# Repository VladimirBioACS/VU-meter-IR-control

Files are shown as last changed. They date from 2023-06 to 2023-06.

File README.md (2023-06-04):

# VU-Meter digital control firmware
This is a simple firmware for the Audio VU meter. The firmware implements the IR remote control of the device.

## System architecture

The picture below shows top-level system architecture:

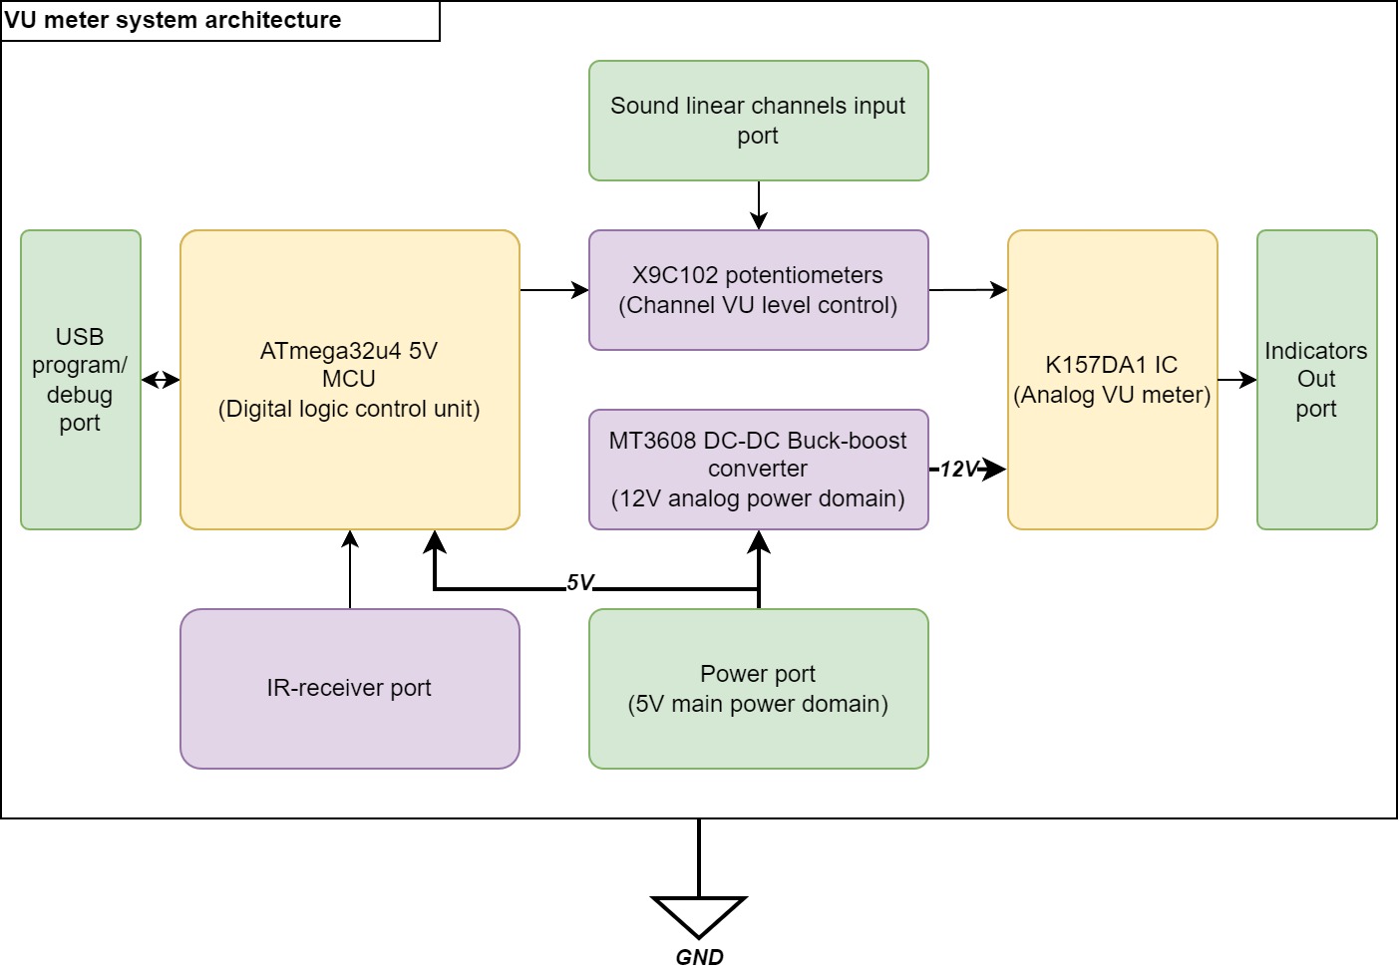
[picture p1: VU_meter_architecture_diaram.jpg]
System diagram


- USB program/debug port is used for programming and debugging process. It is disabled during normal operation. To use debug functionality the specified macro should be set in the code;
- ATMega32u4 5V MCU - digital logic control unit. Main part of the digital control subsystem. Controls the X9C102 potentiometers and receives controlling CMD`s via IR-receiver port;
- K157DA1 IC: analog VU meter IC. Used as a controller for the analog sound level indication gauges;
- MT3608 DC-DC Buck-boost converter: main power supply for the K157DA1 IC domain. Outputs 12V DC. As input takes 5V from power port and boost it to the 12V;
- X9C102 ICs: digital potentiometers (0 - 100K). Used as power limiter for the sound linear channels. The resistance range of the X9C102 IC`s limited with software to the 30K max. One X9C102 step equals to 3K. Maximum value: 42K; minimum value: 3K (14 steps in general);
- IR-receiver port: 2-pin port, used for  IR-receiving diode connection;
- Power port: main power port for the device (strictly 5V);
- Sound linear channel input port: input port for left and right sound channels;
- Indicators Out port: output port for the analog sound level indication gauges.

## Device 3D model

The picture below shows 3D model of the VU-meter device

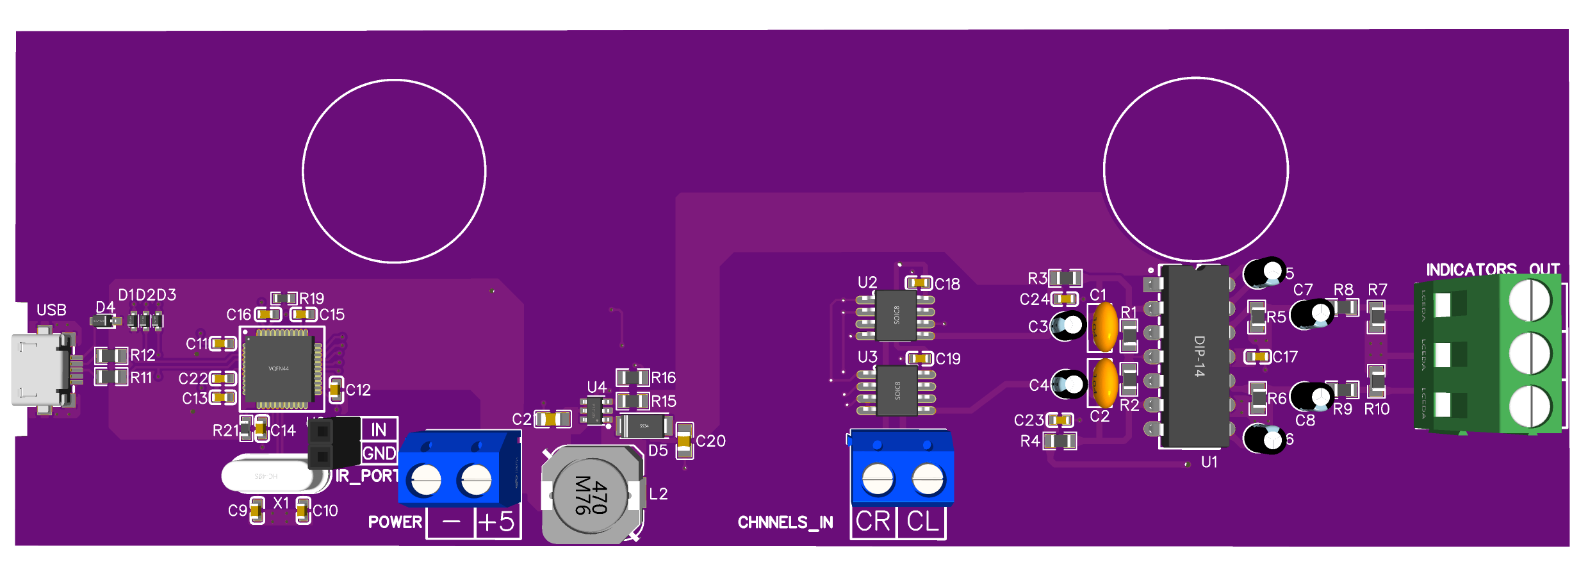
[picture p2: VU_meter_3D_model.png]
3D diagram


## Project structure

Root folder contains platformio.ini configuration and additional (README.md, pictures, build.py etc) files.
Folder structure:
- **src**: contains project source files;
- **include**: contains project header files;
- **lib**: contains project specific (private) libraries;
- **test**: contains unit tests;
- **PCB_designb**: contains HW related files (schematic; gerbers and EasyEDA project);
- **.vscode**: contains VS Code config;
- **Profiler_application**: contains the profiler application flow for the Node-RED.

## How to add custom IR-Remote

To add a remote to control the device you need:
- Set the **DEBUG_PRINTER** and **DEBUG_IR_FULL_INFO** options to **STD_ON**
- Upload firmware to the device and open serial port;
- Start pressing buttons on the remote. You should get a debug output with full information about the IR protocol. The necessary info are stored in IR CMD values;
- Save the IR CMD values and write it to the **protocol.h** header file to the corresponding #define constant.

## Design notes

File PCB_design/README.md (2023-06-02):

# VU-meter Schematic
This folder contains schematic; gerbers and EasyEDA project files for VU-meter device.

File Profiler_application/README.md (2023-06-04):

# Profiler application

This folder contains the Node-RED flow for the profiler application. The Node-RED (https://nodered.org/docs/getting-started/local) need to be installed on the host machine in order to run this application flow.

To import project into Node-RED use this guide: https://nodered.org/docs/user-guide/editor/workspace/import-export

## Profiler application demo:

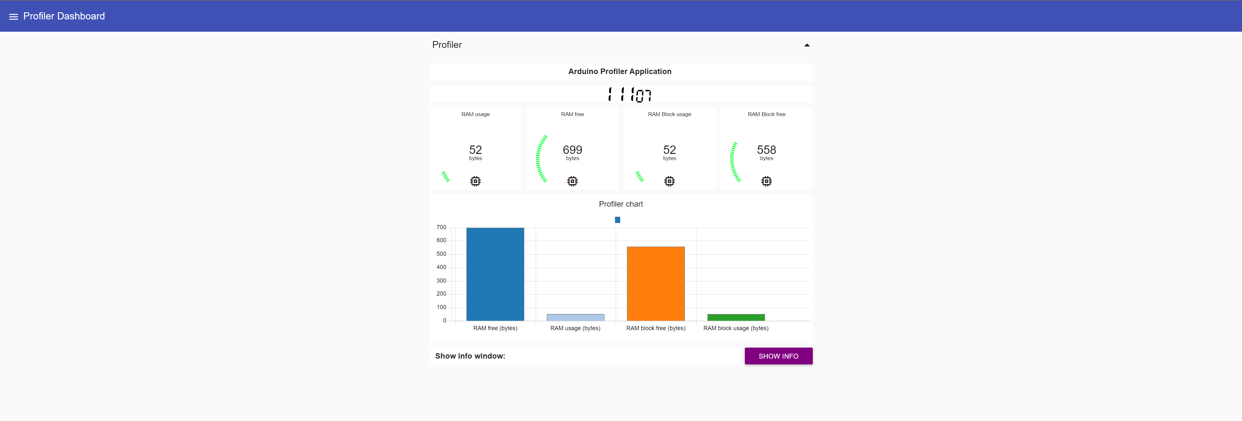
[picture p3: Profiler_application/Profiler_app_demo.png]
Profiler app demo


## Profiler description

Simple profiler for Arduino applications, based on Node-RED and ArduinoProfiler + ArduinoJson libs.
Profiler receives JSON data from target device from UART interface. The data contains:

- RAM usage in bytes;
- Free RAM in bytes;
- RAM block usage in bytes;
- Free RAM block in bytes.

## How to use profiler

To be able to use profiler you need to perform next steps:

- Enable the **ARDUINO_PROFILER** and **DEBUG_PRINTER** options in the **main.h** file;
- Compile and upload firmware to the target device;
- Install the Node-RED on your host machine, using the guide provided in first section, and import the profiler.json to the Node-RED environmetn (use the guide provided in first section);
- Check the COM port to which target device is connected and change it (if needed) in profiler.json UART configuration;
- Connect the target device to PC and  open the web application with http://localhost:1880/ui.

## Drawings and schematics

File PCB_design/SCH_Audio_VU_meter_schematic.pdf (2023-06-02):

A | A

1

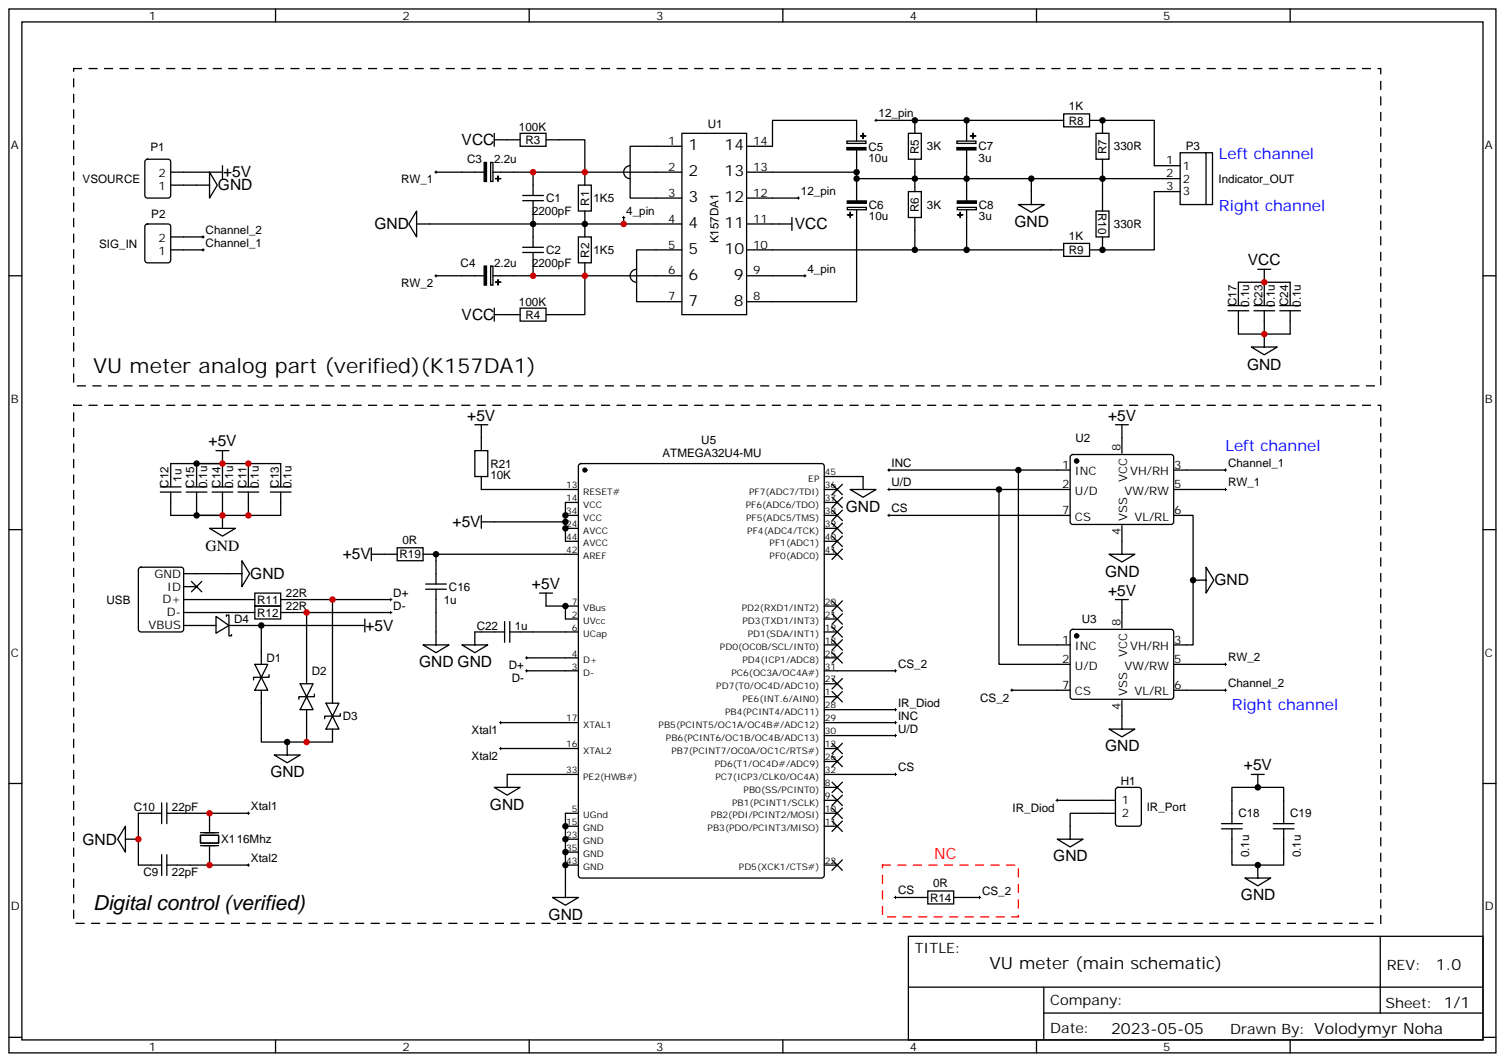
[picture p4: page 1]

VU meter analog part (verified)(K157DA1)

Drawn By: Volodymyr Noha

A | A

1

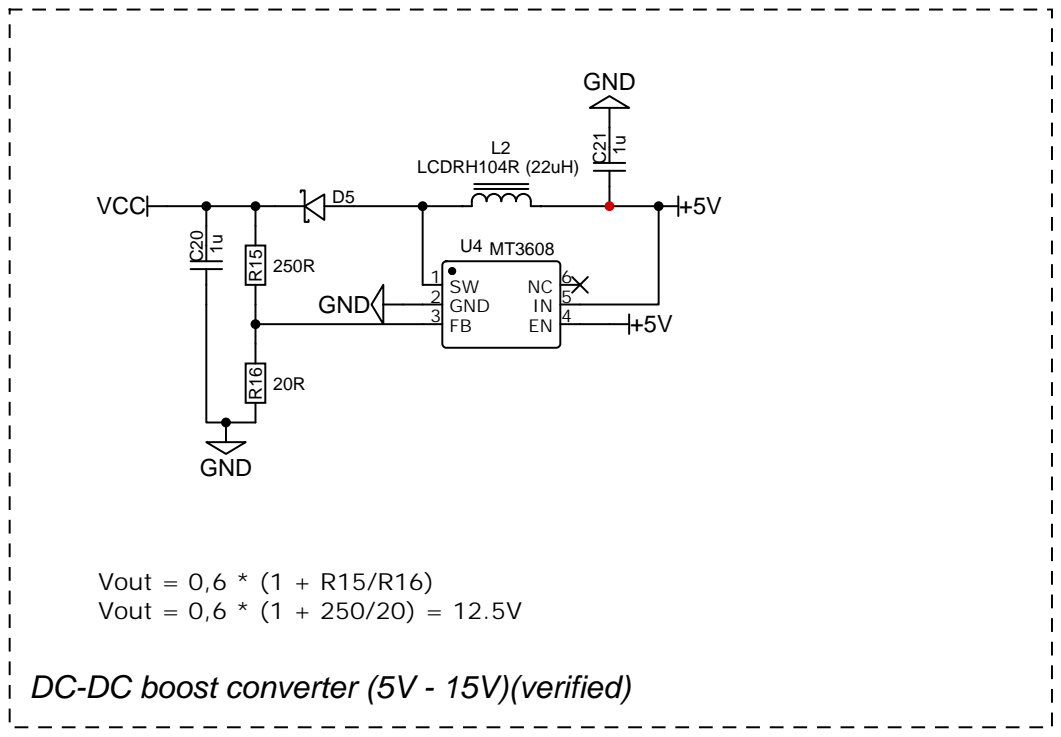
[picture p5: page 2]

Vout = 0,6 * (1 + R15/R16)
Vout = 0,6 * (1 + 250/20) = 12.5V
DC-DC boost converter (5V - 15V)(verified)

Drawn By: Volodymyr Noha

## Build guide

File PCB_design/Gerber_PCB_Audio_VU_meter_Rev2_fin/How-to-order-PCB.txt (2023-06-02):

How to Order PCB

Please refer to:
https://docs.easyeda.com/en/PCB/Order-PCB

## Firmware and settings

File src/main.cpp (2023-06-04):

/**
 __      ___    _        __  __ ______ _______ ______ _____
\ \    / / |  | |      |  \/  |  ____|__   __|  ____|  __ \
 \ \  / /| |  | |______| \  / | |__     | |  | |__  | |__) |
  \ \/ / | |  | |______| |\/| |  __|    | |  |  __| |  _  /
   \  /  | |__| |      | |  | | |____   | |  | |____| | \ \
    \/    \____/       |_|  |_|______|  |_|  |______|_|  \_\

**********************************************************************************************************************
*    @file           : main.cpp
*    @brief          : main program body
**********************************************************************************************************************
*    @author     Volodymyr Noha
*    @license    MIT (see License.txt)
*
*    @description:
*    This is a simple firmware for the Audio VU meter. The firmware implements the IR remote control of the device
*
*    @section  HISTORY
*    v1.0  - First version
*
**********************************************************************************************************************
*/

/*********************************************************************************************************************/
/*-----------------------------------------------------Includes------------------------------------------------------*/
/*********************************************************************************************************************/

#include <Arduino.h>
#include "EEPROMStore.h"
#include "X9C102_potentiometer.h"
#include "IRremote.h"
#include "cs_port_LL.h"
#include "protocol.h"

#if (DEBUG_PRINTER == STD_ON || SOFTWARE_SERIAL_DEBUG == STD_ON)
#include "platform.h"
#endif

#if (AVR_WDT_ENABLE == STD_ON)
#include "avr/wdt.h"
#endif

#include "main.h"
/*********************************************************************************************************************/
/*------------------------------------------------------Macros-------------------------------------------------------*/
/*********************************************************************************************************************/

/* Serial log setup*/
#if (DEBUG_PRINTER == STD_ON && SOFTWARE_SERIAL_DEBUG == STD_OFF)

#define DEBUG_SETUP(baudrate) Serial.begin(baudrate)
#define DEBUG(string) Serial.print(string)
#define DEBUG_NL(string_nln) Serial.println(string_nln)

#pragma message("Hardware serial debug enabled")

#elif (DEBUG_PRINTER == STD_ON && SOFTWARE_SERIAL_DEBUG == STD_ON)

#include "SoftwareSerial.h"

SoftwareSerial softSerial(DEBUG_RX, DEBUG_TX);

#define DEBUG_SETUP(baudrate) softSerial.begin(baudrate)
#define DEBUG(string) softSerial.print(string)
#define DEBUG_NL(string_nln) softSerial.println(string_nln)

#pragma message("Software serial debug enabled")

#else

#define DEBUG_SETUP(baudrate)
#define DEBUG(string)
#define DEBUG_NL(string_nln)
#pragma message("Debug disabled")

#endif

/*********************************************************************************************************************/
/*------------------------------------------------------Classes------------------------------------------------------*/
/*********************************************************************************************************************/

IRrecv irreciver(RECEIVER_GPIO);
X9C102_potentiometer potentiometer(UD_POTENTIOMETER_GPIO, INC_POTENTIOMETER_GPIO);

EEPROMStore<ChannelsConfiguration> Configuration;

#if(ARDUINO_PROFILER == STD_ON && DEBUG_PRINTER == STD_ON)

#include "Profiler.h"
#include "ArduinoJson-v6.19.4.h"

Profiler profiler;

#endif

/*********************************************************************************************************************/
/*------------------------------------------------Function Prototypes------------------------------------------------*/
/*********************************************************************************************************************/

static void potentiometerChannelSelect(int option);
static bool storeEepromConfig(uint8_t left_channel_value, uint8_t right_channel_value);
static void irDataReceive(void);

#if(DEBUG_PRINTER == STD_ON || SOFTWARE_SERIAL_DEBUG == STD_ON)
static void showSystemInfo(void);
#endif

#if (DEBUG_PRINTER == STD_ON && DEBUG_IR_FULL_INFO == STD_ON)
static void irReceiveCmdInfo();
#endif

/*********************************************************************************************************************/
/*---------------------------------------------Function Implementations----------------------------------------------*/
/*********************************************************************************************************************/

#if (DEBUG_PRINTER == STD_ON || SOFTWARE_SERIAL_DEBUG == STD_ON)
/**
 * @brief This function prints system info via UART
 * @param argument: None
 * @retval None
 */
static void showSystemInfo(void)
{

  DEBUG_NL("=====PLATFORM INFO START=====");

  DEBUG("[MCU]: ");
  DEBUG_NL(MCU);

  DEBUG("[FIRMWARE VERSION]: ");
  DEBUG_NL(FIRMWARE_VERSION);

  DEBUG("[DEVICE DESCRIPTION]: ");
  DEBUG_NL(DEVICE_DESCRIPTION);

  DEBUG("[EEPROM VOLUME]: ");
  DEBUG(EEPROM_VOLUME);
  DEBUG_NL(" bytes");

  DEBUG("[FLASH VOLUME]: ");
  DEBUG(FLASH_VOLUME);
  DEBUG_NL(" bytes");

  DEBUG("[RAM VOLUME]: ");
  DEBUG(RAM_VOLUME);
  DEBUG_NL(" bytes");

  DEBUG("[POTENTIOMETER RESOLUTION]");
  DEBUG(POTENTIOMETER_RESOLUTION);
  DEBUG_NL(" KOhm");

  DEBUG("[POTENTIOMETER MAX RESISTANCE]: ");
  DEBUG(MAX_RESISTANCE);
  DEBUG_NL(" KOhm");

  DEBUG("[POTENTIOMETER MIN RESISTANCE]: ");
  DEBUG(MIN_RESISTANCE);
  DEBUG_NL(" KOhm");

#if (AVR_WDT_ENABLE == STD_ON)
  DEBUG_NL("[OPTION]: Watchdog timer: [ENABLED]");
  DEBUG("[OPTION]: Watchdog config: ");
  DEBUG_NL(WDT_TRIGGER_TIME);
#endif

#if (DEBUG_PRINTER == STD_ON)
  DEBUG_NL("[OPTION]: USB Debug printer: [ENABLED]");
#endif

#if (SOFTWARE_SERIAL_DEBUG == STD_ON)
  DEBUG_NL("[OPTION]: Software serial Debug printer: [ENABLED]");
#endif

#if (INIT_POTENTIOMETERS_WITH_EEPROM_VAL == STD_ON)
  DEBUG_NL("[OPTION]: Potentiometer initialization from EEPROM: [ENABLED]");

  DEBUG("[OPTION]: Current EEPROM value for Left channel: ");
  DEBUG_NL(Configuration.Data.channel_left_step_value);

  DEBUG("[OPTION]: Current EEPROM value for Right channel: ");
  DEBUG_NL(Configuration.Data.channel_right_step_value);
#endif

#if (EEPROM_CHECK_TASK_ENABLE == STD_ON)
  DEBUG_NL("[OPTION]: EEPROM memory check task: [ENABLED]");
#endif

#if (ARDUINO_PROFILER == STD_ON)
  DEBUG_NL("[OPTION]: Arduino profiler: [ENABLED]");
#endif

}

#endif

#if (DEBUG_PRINTER == STD_ON && DEBUG_IR_FULL_INFO == STD_ON)
/**
 * @brief Function implements the received IR data parsing. Mainly used for the debug
 * @param argument: None
 * @retval None
 */
static void irReceiveCmdInfo()
{
  if (irreciver.decode()) {
    DEBUG_NL("Basic info:");
    irreciver.printIRResultMinimal(&Serial);
    DEBUG_NL();
    DEBUG_NL("Basic raw format:");
    irreciver.printIRResultRawFormatted(&Serial);
    DEBUG_NL();
    DEBUG_NL("Result as a C variable:");
    irreciver.printIRResultAsCVariables(&Serial);
    DEBUG_NL();
  }

  irreciver.resume();
}
#endif

/**
 * @brief Function implements the EEPROM config storage and returns status after EEPROM write
 * @param argument: uint8_t left_channel_value, uint8_t right_channel_value
 * @retval None
 */
static bool storeEepromConfig(uint8_t left_channel_value, uint8_t right_channel_value)
{
  Configuration.Data.channel_left_step_value = left_channel_value;
  Configuration.Data.channel_right_step_value = right_channel_value;

  bool eeprom_status_f = Configuration.Save();

  return eeprom_status_f;
}

/**
 * @brief Function implements the selection mechanism for left and Right channel potentiometers
 * @param argument: int option
 * @retval None
 */
static void potentiometerChannelSelect(int option)
{
  switch (option) {
  case LEFT_CHANNEL_SELECT:
    CSportSet(LEFT_CHANNEL_SELECT);
    break;

  case RIGHT_CHANNEL_SELECT:
    CSportSet(RIGHT_CHANNEL_SELECT);
    break;

  case RELEASE_CHANNELS_CS_LINES: /*release the potentiometer CS line to avoid sporadic value change*/
    CSportSet(RELEASE_CHANNELS_CS_LINES);
    break;

  case SELECT_ALL_CS_CHANNELS:
    CSportSet(SELECT_ALL_CS_CHANNELS);
    break;

  default:
    break;
  }
}

/**
 * @brief Function implements the reception of the IR CMD and contains its processing logic
 * @param argument: None
 * @retval None
 */
static void irDataReceive(void)
{
  static uint8_t left_channel_value = Configuration.Data.channel_left_step_value;
  static uint8_t right_channel_value = Configuration.Data.channel_right_step_value;
  static uint8_t channel_select_f = CHANNEL_SELECTION_IDLE_F;

  /* should be tested */
  if (right_channel_value < POTENTIOMETER_LOW_BOUNDRY) {
    right_channel_value = POTENTIOMETER_LOW_BOUNDRY;
  }

  if (left_channel_value < POTENTIOMETER_LOW_BOUNDRY) {
    left_channel_value = POTENTIOMETER_LOW_BOUNDRY;
  }

  if (irreciver.decode()) {

    if (irreciver.decodedIRData.protocol != UNKNOWN) {
      uint32_t received_cmd = irreciver.decodedIRData.decodedRawData;

      switch (received_cmd) {
      
      case SELECT_RIGHT_CHANNEL_CMD_RAW:
        
        DEBUG_NL("[CMD received]: Right channel selected");

        channel_select_f = RIGHT_CHANNEL_SELECT_F;
        potentiometerChannelSelect(RIGHT_CHANNEL_SELECT);

        break;

      case SELECT_LEFT_CHANNEL_CMD_RAW:
        
        DEBUG_NL("[CMD received]: Left channel selected");

        channel_select_f = LEFT_CHANNEL_SELECT_F;
        potentiometerChannelSelect(LEFT_CHANNEL_SELECT);

        break;

      case COMMIT_CHANGES_CMD_RAW:
        
        DEBUG_NL("[CMD received]: Changes commited");

        potentiometerChannelSelect(RELEASE_CHANNELS_CS_LINES);
        channel_select_f = CHANNEL_SELECTION_IDLE_F;

        if (storeEepromConfig(left_channel_value, right_channel_value)) {
          DEBUG_NL("Configuration stored in eeprom");
          DEBUG_NL("EEPROM storage content: ");

          DEBUG("Left channel step value: ");
          DEBUG(Configuration.Data.channel_left_step_value);
          DEBUG_NL("");

          DEBUG("Right channel step value: ");
          DEBUG(Configuration.Data.channel_right_step_value);
          DEBUG_NL("");
        }

        else {
          DEBUG_NL("EEPROM data did not changed");
        }

        break;

      case INCREASE_VU_VALUE_CMD_RAW:
        
        DEBUG_NL("[CMD received]: VU value UP");

        if (channel_select_f == LEFT_CHANNEL_SELECT_F) {
          --left_channel_value;                         /* Decrease left channel potentiometer value to increase the left channel signal magnitude */

          if (left_channel_value >= POTENTIOMETER_LOW_BOUNDRY) {
            potentiometer.potentiometerSetVal(left_channel_value, DIRECTION_DOWN);
            DEBUG_NL(left_channel_value);
          }

          else {
            left_channel_value = POTENTIOMETER_LOW_BOUNDRY;
          }
        }

        if (channel_select_f == RIGHT_CHANNEL_SELECT_F) {
          --right_channel_value;                        /* Decrease right channel potentiometer value to increase the right channel signal magnitude */

          if (right_channel_value >= POTENTIOMETER_LOW_BOUNDRY) {
            potentiometer.potentiometerSetVal(right_channel_value, DIRECTION_UP);
            DEBUG_NL(right_channel_value);
          } else {
            right_channel_value = POTENTIOMETER_LOW_BOUNDRY;
          }
        } else {
          // empty
        }

        break;

      case DECREASE_VU_VALUE_CMD_RAW:
        
        DEBUG_NL("[CMD received]: VU value DOWN");

        if (channel_select_f == LEFT_CHANNEL_SELECT_F) {
          ++left_channel_value;                         /* Increase left channel potentiometer value to decrease the left channel signal magnitude */

          if (left_channel_value <= POTENTIOMETER_HIGH_BOUNDRY) {
            potentiometer.potentiometerSetVal(left_channel_value, DIRECTION_DOWN);
            DEBUG_NL(left_channel_value);
          } else {
            left_channel_value = POTENTIOMETER_HIGH_BOUNDRY;
          }
        }

        if (channel_select_f == RIGHT_CHANNEL_SELECT_F) {
          ++right_channel_value;                        /* Increase right channel potentiometer value to decrease the right channel signal magnitude */

          if (right_channel_value <= POTENTIOMETER_HIGH_BOUNDRY) {
            potentiometer.potentiometerSetVal(right_channel_value, DIRECTION_UP);
            DEBUG_NL(right_channel_value);
          } else {
            right_channel_value = POTENTIOMETER_HIGH_BOUNDRY;
          }
        } else {
          // empty
        }

        break;

      case FACTORY_RESET_VU_VAL_CMD_RAW:

        potentiometerChannelSelect(RIGHT_CHANNEL_SELECT);
        right_channel_value = POTETNIOMETER_RESET_VALUE;
        potentiometer.potentiometerSetVal(right_channel_value, DIRECTION_UP);

        potentiometerChannelSelect(LEFT_CHANNEL_SELECT);
        left_channel_value = POTETNIOMETER_RESET_VALUE;
        potentiometer.potentiometerSetVal(left_channel_value, DIRECTION_DOWN);

        potentiometerChannelSelect(RELEASE_CHANNELS_CS_LINES);

        if (storeEepromConfig(left_channel_value, right_channel_value)) {
          DEBUG_NL("Factory reset potentiometer values");
          DEBUG_NL("EEPROM storage content: ");

          DEBUG("Left channel step value: ");
          DEBUG(Configuration.Data.channel_left_step_value);
          DEBUG_NL("");

          DEBUG("Right channel step value: ");
          DEBUG(Configuration.Data.channel_right_step_value);
          DEBUG_NL("");

        } else {
          DEBUG_NL("EEPROM Factory reset");
          DEBUG_NL("EEPROM data did not changed");
        }

        break;


/*Debug info*/
#if (DEBUG_PRINTER == STD_ON || SOFTWARE_SERIAL_DEBUG == STD_ON)
      case PRINT_DEBUG_INFO_CMD_RAW:
        showSystemInfo();
        break;
#endif

      default:
        DEBUG_NL("[CMD received]: Unknown command");
        break;
      }
    } else {
      DEBUG_NL("Unknown protocol");
    }
  }

/**
 * EEPROM check task
 * This task checks the EEPROM values every 5 minutes
 * This task should re-write EEPROM with actual potentiometer values
 * in case if EEPROM will not be updated by pressing "OK" button
*/
#if(EEPROM_CHECK_TASK_ENABLE == STD_ON)
  static uint32_t old_time_eeprom_check_value = millis();

  if ((millis() - old_time_eeprom_check_value) > DELAY_EEPROM_CHECK) {          /* Timer for non-blocking delay */
    if (storeEepromConfig(left_channel_value, right_channel_value)) {
      DEBUG_NL("EEPROM Check task");
      DEBUG_NL("EEPROM stored");
      DEBUG_NL("EEPROM storage content: ");

      DEBUG("Left channel step value: ");
      DEBUG(Configuration.Data.channel_left_step_value);
      DEBUG_NL("");

      DEBUG("Right channel step value: ");
      DEBUG(Configuration.Data.channel_right_step_value);
      DEBUG_NL("");

    } else {
      DEBUG_NL("EEPROM Check task");
      DEBUG_NL("EEPROM data did not changed");
    }

    old_time_eeprom_check_value = millis();
  }
#endif

  irreciver.resume();
}

/**
 * @brief Main setup function
 * @param argument: None
 * @retval None
 */
void setup()
{
/* WDG initialization */
#if (AVR_WDT_ENABLE == STD_ON)
  wdt_enable(WDT_TRIGGER_TIME); /* WDTO_4S => 4 second timeout. */
#endif

  DEBUG_SETUP(BAUDRATE);

  /* GPIO initialization */
  CSportInit();

  /* External devices initialization */
  irreciver.enableIRIn();
  potentiometer.potentiometerInit();

#if (INIT_POTENTIOMETERS_WITH_EEPROM_VAL == STD_ON)

  potentiometerChannelSelect(LEFT_CHANNEL_SELECT);
  potentiometer.potentiometerSetVal(Configuration.Data.channel_left_step_value, DIRECTION_DOWN);

  potentiometerChannelSelect(RIGHT_CHANNEL_SELECT);
  potentiometer.potentiometerSetVal(Configuration.Data.channel_right_step_value, DIRECTION_UP);

#endif

  potentiometerChannelSelect(RELEASE_CHANNELS_CS_LINES);

}

/**
 * @brief Main superloop function
 * @param argument: None
 * @retval None
 */
void loop()
{
  /* Main loop */
  static uint32_t old_tim_value = millis();

  if ((millis() - old_tim_value) > DELAY_PERIOD) {   /* Timer for non-blocking delay */

#if (DEBUG_PRINTER == STD_ON && DEBUG_IR_FULL_INFO == STD_ON)
    irReceiveCmdInfo();
#else
    irDataReceive();
#endif

#if(ARDUINO_PROFILER == STD_ON && DEBUG_PRINTER == STD_ON)

  StaticJsonDocument<32> doc;

  doc["ram_usage"] = profiler.getRAMUsage();
  doc["block_usage"] = profiler.getBlockUsage();
  doc["free_block"] = profiler.getFreeBlock();
  doc["free_ram"] = profiler.getFreeRAM();

  serializeJson(doc, Serial);
  DEBUG_NL(" ");

#endif

    old_tim_value = millis();
  }

/* WDG pet */
#if (AVR_WDT_ENABLE == STD_ON)
  wdt_reset();
#endif
}

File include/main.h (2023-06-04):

/**
**********************************************************************************************************************
*    @file           : main.h
*    @brief          : main program header
**********************************************************************************************************************
*    @author     Volodymyr Noha
*    @license    MIT (see License.txt)
*
*    @description:
*    This is a simple firmware for the Audio VU meter. The firmware implements the IR remote control of the device.
*    Header contains all function definitions and main program configs
*
*    @section  HISTORY
*    v1.0  - First version
*
**********************************************************************************************************************
*/

#ifndef MAIN_H_
#define MAIN_H_

/*********************************************************************************************************************/
/*------------------------------------------------------Configs------------------------------------------------------*/
/*********************************************************************************************************************/

#define BAUDRATE                            (unsigned long)(115200)

#define RECEIVER_GPIO                       (uint_fast8_t)(8)
#define LEFT_CHANNEL                        (uint8_t)(13)
#define RIGHT_CHANNEL                       (uint8_t)(5)
#define UD_POTENTIOMETER_GPIO               (uint8_t)(10)
#define INC_POTENTIOMETER_GPIO              (uint8_t)(9)

#define DEBUG_RX                            (uint8_t)(7)              /* Software serial debugger GPIO RX pin*/
#define DEBUG_TX                            (uint8_t)(6)              /* Software serial debugger GPIO TX pin*/

#define CHANNEL_SELECTED                    (uint8_t)(0x0)
#define CHANNEL_UNSELECTED                  (uint8_t)(0x1)

#define STD_ON                              (1)
#define STD_OFF                             (0)

#define DEBUG_PRINTER                       (STD_OFF)
#define SOFTWARE_SERIAL_DEBUG               (STD_OFF)
#define DEBUG_IR_FULL_INFO                  (STD_OFF)
#define AVR_WDT_ENABLE                      (STD_ON)
#define INIT_POTENTIOMETERS_WITH_EEPROM_VAL (STD_ON)
#define EEPROM_CHECK_TASK_ENABLE            (STD_ON)
#define ARDUINO_PROFILER                    (STD_OFF)

#define POTENTIOMETER_LOW_BOUNDRY           (uint8_t)(1)              /* 3 KOhm */
#define POTENTIOMETER_HIGH_BOUNDRY          (uint8_t)(14)             /*42 KOhm with step of 3 KOhm (14 * 3 = 42)*/

#define POTETNIOMETER_RESET_VALUE           (uint8_t)(5)
#define DELAY_PERIOD                        (int)(100)                /* 100ms delay for non-blocking timer */
#define DELAY_EEPROM_CHECK                  (1000UL * 60 * 5)         /* delay 5 minutes */
#define WDT_TRIGGER_TIME                    WDTO_4S

/*********************************************************************************************************************/
/*--------------------------------------------------------PVs--------------------------------------------------------*/
/*********************************************************************************************************************/

/*Parameters to be stored in the EEPROM memory*/
struct ChannelsConfiguration 
{
  uint8_t channel_left_step_value;
  uint8_t channel_right_step_value;

  void Reset()
  {
    channel_left_step_value = POTETNIOMETER_RESET_VALUE;
    channel_right_step_value = POTETNIOMETER_RESET_VALUE;
  }
};

/*enumeration for potentiometers CS line selection*/
enum channelsState 
{
  LEFT_CHANNEL_SELECT,
  RIGHT_CHANNEL_SELECT,
  RELEASE_CHANNELS_CS_LINES,
  SELECT_ALL_CS_CHANNELS
};

/*enumeration for channel selection flags*/
enum channelSelectFlags 
{
  LEFT_CHANNEL_SELECT_F = 1 << 0,
  RIGHT_CHANNEL_SELECT_F = 1 << 1,
  CHANNEL_SELECTION_IDLE_F = 1 << 2
};

#endif

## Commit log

2023-05-22 Bug fixed: wrong logic in boundry value processing
    [main.cpp]
2023-05-26 Added: - Low level port control for CS line selection
    Modified:
    - CS line selection mechanism
    Fixed:
    - Bug with non-blocking delay. Logic for millis() was changed
    [X9C102_potentiometer.cpp, cs_port_LL.cpp, main.cpp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]
2023-05-26 Fixed path in #include avr/wdt.h
    [main.cpp, main.h]
2023-05-27 Feature added:
    - EEPROM checking task. This task should monitor the EEPROM
    refresh it every "set period" of time to avoid loss of
    config. In case if EEPROM content did not changed the
    checking task will not rewrite it and left as is.
    Working in non-blocking mode. Takes 10ms to check and
    write EEPROM.
    [main.cpp, main.h]
2023-06-02 Added: - PCB_design folder with HW related files (gerbers; schematic and PCB design)
    [Drill_NPTH_Through.DRL, Drill_PTH_Through.DRL, Drill_PTH_Through_Via.DRL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]
2023-06-02 Device 3D model updated
2023-06-02 Device 3D model name fixed
2023-06-04 [VU-meter firmware V1.0 major update]
    Added:
    - Potentiometer value factory reset function;
    - New comments in source and header files
    - README.md;
    - Profiler_application/README.md;
    - X9C102_potentiometer.c: public interface dir parameter modified
    - Code style in general;
    - Variable and consts naming
    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
    [X9C102_potentiometer.cpp, cs_port_LL.cpp, main.cpp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]
